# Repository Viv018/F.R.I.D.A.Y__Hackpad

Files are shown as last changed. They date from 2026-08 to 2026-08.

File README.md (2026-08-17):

# F.R.I.D.A.Y__Hackpad
This is a Macro pad with a 3x3 key pad along with a rotary encoder and a 0.91 QLED screen for my HACKCLUB project
# F.R.I.D.A.Y

A custom 3×3 macropad with a rotary encoder, 0.91" OLED, and per-key SK6812 RGB lighting, built around the Seeeduino XIAO.

I named it F.R.I.D.A.Y because I wanted something that feels like a helpful little assistant sitting on my desk and cause i am a big marvel fan.

### Features
- 9 mechanical switches (3×3 matrix)
- Rotary encoder with push button
- 0.91" 128×32 OLED display
- 8× SK6812MINI-E reverse-mount RGB LEDs
- Seeed XIAO RP2040
- Fully open source

### Photos

**Schematic**
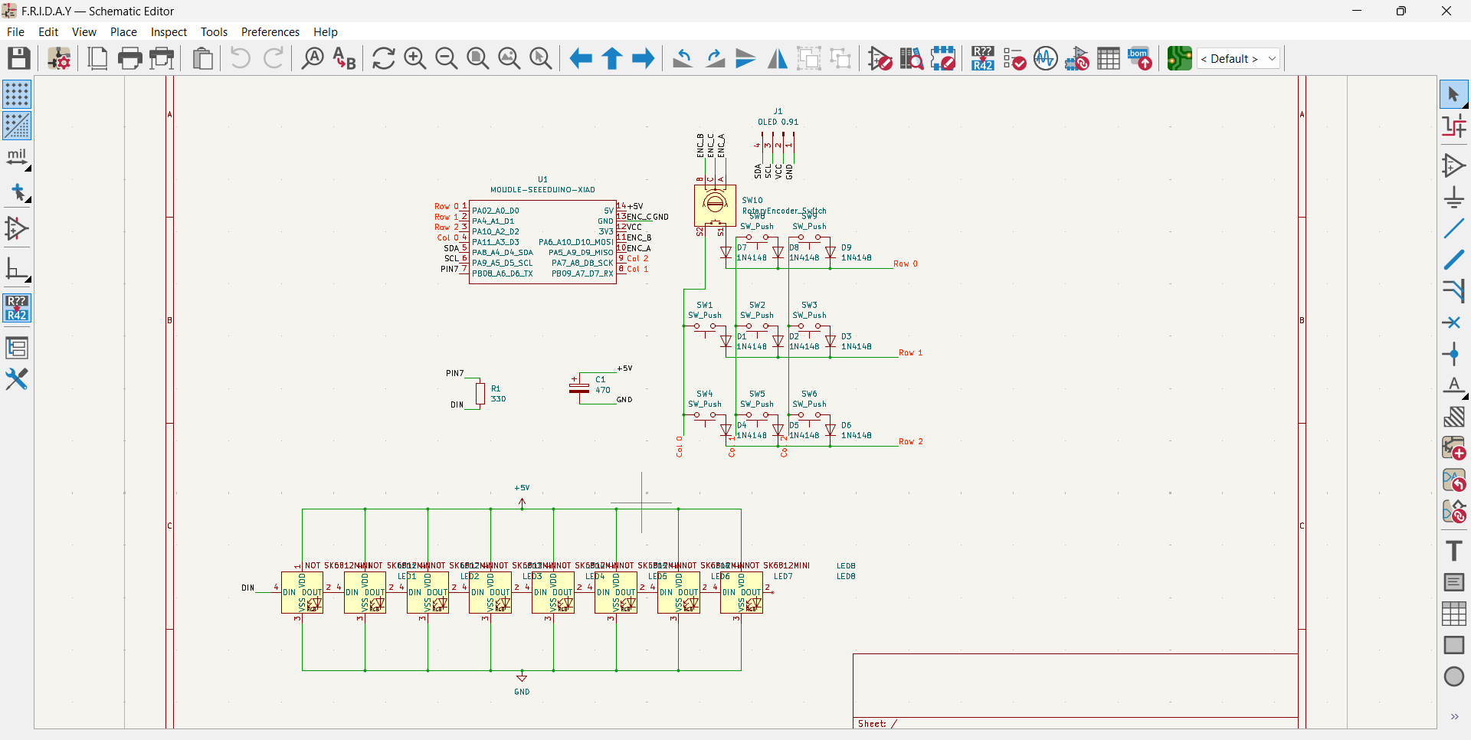
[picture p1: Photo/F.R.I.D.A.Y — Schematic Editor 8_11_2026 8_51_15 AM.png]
Schematic


**PCB**
PCB

**Case**
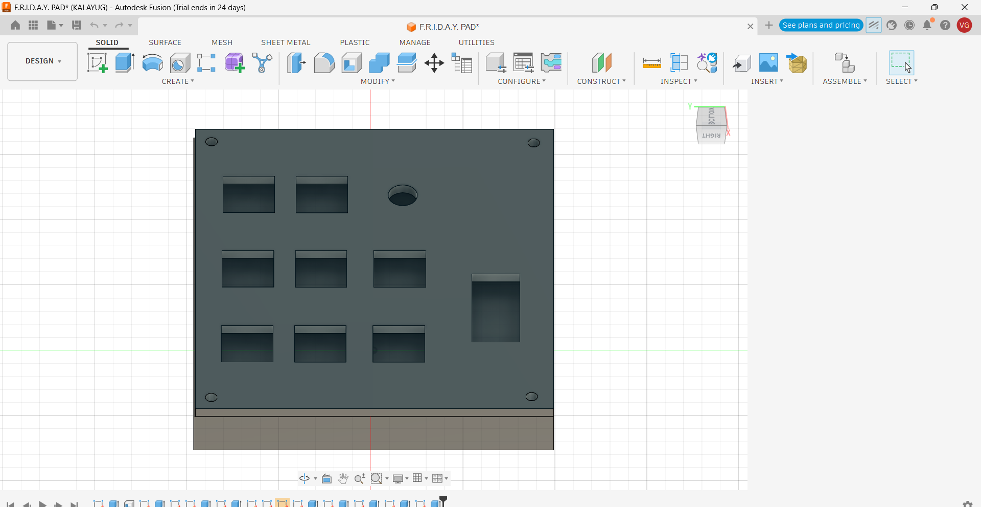
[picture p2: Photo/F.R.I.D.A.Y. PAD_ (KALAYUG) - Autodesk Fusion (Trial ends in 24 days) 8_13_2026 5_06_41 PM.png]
Case


### Bill of Materials

| Part | Quantity | Notes |
|---|---|---|
| Seeeduino XIAO | 1 | RP2040 version |
| MX-style switches | 9 | Any MX compatible |
| SK6812MINI-E | 8 | Reverse mount |
| 1N4148 diodes | 9 | |
| Rotary Encoder (EC11) | 1 | With push switch |
| 0.91" OLED | 1 | I2C, 128×32 |
| Keycaps | 9 | 1u |
| M3 screws + heat-set inserts | 4 | For the case |

### Firmware
This project uses **QMK**

The firmware is located in the `/Firmware` folder.

### Case
The case is a simple two-part sandwich design made in Fusion 360.  
STL/STEP files are available in the `/CAD` and `/production` folders.

### Credits
Designed for Hack Club’s Hackpad program by BATMANNN BABYYY

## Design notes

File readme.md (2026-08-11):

# F.R.I.D.A.Y.

This is my custom macropad, F.R.I.D.A.Y. I designed the schematic and PCB
myself in KiCad and wrote the firmware on top of QMK. It's a 3x3 key
matrix (9 keys total, one of them being the rotary encoder's own push
switch), plus the encoder for rotation input, a small OLED screen, and
RGB lighting.

## What's on it

- Seeed XIAO RP2040 as the brains
- 3x3 switch matrix (9 keys), with SW10 (the encoder's push button)
  built into the matrix as one of the 9
- A rotary encoder for scrolling / volume / media control
- A 0.91" OLED (128x32) that shows which layer is active
- 8x SK6812 addressable RGB LEDs

## Pin mapping

I worked this out straight from my schematic:

| Net | XIAO pin | RP2040 GPIO |
|---|---|---|
| Row 0 | D0 | GP26 |
| Row 1 | D1 | GP27 |
| Row 2 | D2 | GP28 |
| Col 0 | D3 | GP29 |
| SDA (OLED) | D4 | GP6 |
| SCL (OLED) | D5 | GP7 |
| PIN7 -> DIN (LEDs)  | D6 | GP0 |
| Col 1 | D7 | GP1 |
| Col 2 | D8 | GP2 |
| ENC_A | D9 | GP4 |
| ENC_B | D10 | GP3 |

Key layout, matching the silkscreen on my PCB:

```
[SW10] [SW8] [SW9]     <- SW10 is the encoder's own push button
[SW1]  [SW2] [SW3]
[SW4]  [SW5] [SW6]
```

## Firmware

Built on QMK. There are two layers - a base layer for my everyday keys
and media, and an Fn layer (hold the bottom-right key) for extra
shortcuts. The encoder does volume on the base layer and skips tracks
on the Fn layer. The OLED just shows the current layer for now.

### Building it

```bash
python3 -m pip install qmk
qmk setup
```

Then drop this whole `friday` folder into `~/qmk_firmware/keyboards/friday/`
so it looks like:

```
qmk_firmware/keyboards/friday/
├── keyboard.json
├── config.h
├── rules.mk
├── readme.md
└── keymaps/
    └── default/
        └── keymap.c
```

Compile:

```bash
qmk compile -kb friday -km default
```

That spits out `friday_default.uf2`.

### Flashing

1. Plug the XIAO RP2040 in over USB.
2. Double-tap reset to drop it into UF2 bootloader mode - a drive
   called `RPI-RP2` shows up.
3. Drag `friday_default.uf2` onto that drive. It reboots on its own
   running the new firmware.

## Notes to self

- If a key or the encoder isn't responding, check continuity on that
  net in KiCad first - the pin table above is only as good as the
  actual soldering.
- If the encoder skips two steps per detent (or does nothing), try
  changing `ENCODER_RESOLUTION` in `config.h` between 2 and 4.
- `ENC_C` on the encoder just goes to GND, nothing to configure there.
- RGB is enabled but I haven't bound any keys to control it yet - next
  thing to add.

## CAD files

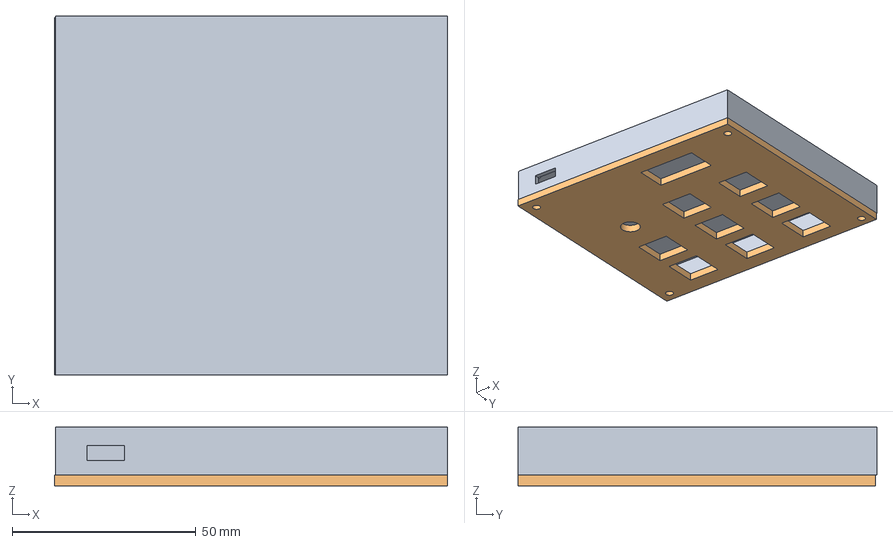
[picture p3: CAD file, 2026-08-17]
CASE/F.R.I.D.A.Y.step
107.1 x 97.8 x 16.0 mm

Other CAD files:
CASE/F.R.I.D.A.Y. PAD.f3d

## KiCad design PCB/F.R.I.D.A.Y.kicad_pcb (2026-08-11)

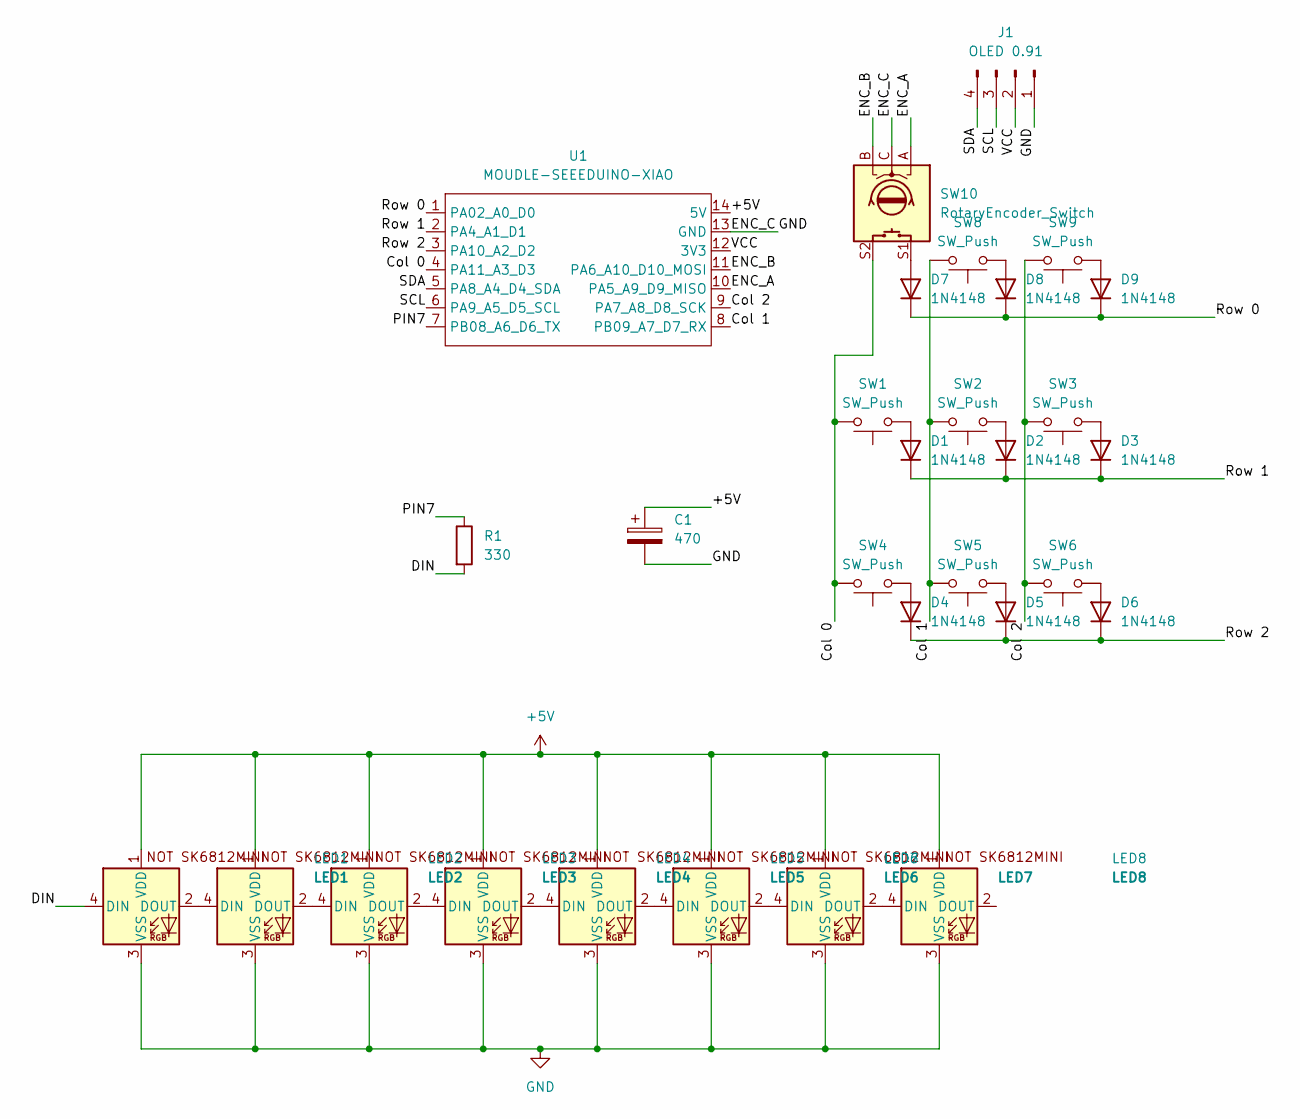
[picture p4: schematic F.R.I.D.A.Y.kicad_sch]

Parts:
C1: 470; CP_Axial_L18.0mm_D6.5mm_P25.00mm_Horizontal
D1, D2, D3, D4, D5, D6, D7, D8, D9: 1N4148; D_DO-35_SOD27_P7.62mm_Horizontal
J1: OLED 0.91; ER_OLEDM0.91_1x-I2C
LED1: LED1; LED_SK6812MINI-E_3.2x2.8mm_P1.5mm_ReverseMount
LED2: LED2; LED_SK6812MINI-E_3.2x2.8mm_P1.5mm_ReverseMount
LED3: LED3; LED_SK6812MINI-E_3.2x2.8mm_P1.5mm_ReverseMount
LED4: LED4; LED_SK6812MINI-E_3.2x2.8mm_P1.5mm_ReverseMount
LED5: LED5; LED_SK6812MINI-E_3.2x2.8mm_P1.5mm_ReverseMount
LED6: LED6; LED_SK6812MINI-E_3.2x2.8mm_P1.5mm_ReverseMount
LED7: LED7; LED_SK6812MINI-E_3.2x2.8mm_P1.5mm_ReverseMount
LED8: LED8; LED_SK6812MINI-E_3.2x2.8mm_P1.5mm_ReverseMount
R1: 330; R_Axial_DIN0207_L6.3mm_D2.5mm_P10.16mm_Horizontal
SW1, SW2, SW3, SW4, SW5, SW6, SW8, SW9: SW_Push; SW_Cherry_MX_1.00u_PCB
SW10: RotaryEncoder_Switch; RotaryEncoder_Alps_EC11E-Switch_Vertical_H20mm
U1: MOUDLE-SEEEDUINO-XIAO; XIAO-Generic-Hybrid-14P-2.54-21X17.8MM

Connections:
+5V: C1.1, LED1.1 (VDD), LED2.1 (VDD), LED3.1 (VDD), LED4.1 (VDD), LED5.1 (VDD), LED6.1 (VDD), LED7.1 (VDD), LED8.1 (VDD), U1.14 (5V)
/Col 0: SW1.2, SW4.2, SW10.S2, U1.4 (PA11_A3_D3)
/Col 1: SW2.2, SW5.2, SW8.2, U1.8 (PB09_A7_D7_RX)
/Col 2: SW3.2, SW6.2, SW9.2, U1.9 (PA7_A8_D8_SCK)
/DIN: LED1.4 (DIN), R1.2
/ENC_A: SW10.A, U1.10 (PA5_A9_D9_MISO)
/ENC_B: SW10.B, U1.11 (PA6_A10_D10_MOSI)
/PIN7: R1.1, U1.7 (PB08_A6_D6_TX)
/Row 0: D7.1 (K), D8.1 (K), D9.1 (K), U1.1 (PA02_A0_D0)
/Row 1: D1.1 (K), D2.1 (K), D3.1 (K), U1.2 (PA4_A1_D1)
/Row 2: D4.1 (K), D5.1 (K), D6.1 (K), U1.3 (PA10_A2_D2)
/SCL: J1.3, U1.6 (PA9_A5_D5_SCL)
/SDA: J1.4, U1.5 (PA8_A4_D4_SDA)
/VCC: J1.2, U1.12 (3V3)
GND: C1.2, J1.1, LED1.3 (VSS), LED2.3 (VSS), LED3.3 (VSS), LED4.3 (VSS), LED5.3 (VSS), LED6.3 (VSS), LED7.3 (VSS), LED8.3 (VSS), SW10.C, U1.13 (GND)
unnamed: D1.2 (A), SW1.1
unnamed: D2.2 (A), SW2.1
unnamed: D3.2 (A), SW3.1
unnamed: D4.2 (A), SW4.1
unnamed: D5.2 (A), SW5.1
unnamed: D6.2 (A), SW6.1
unnamed: D7.2 (A), SW10.S1
unnamed: D8.2 (A), SW8.1
unnamed: D9.2 (A), SW9.1
unnamed: LED1.2 (DOUT), LED2.4 (DIN)
unnamed: LED2.2 (DOUT), LED3.4 (DIN)
unnamed: LED3.2 (DOUT), LED4.4 (DIN)
unnamed: LED4.2 (DOUT), LED5.4 (DIN)
unnamed: LED5.2 (DOUT), LED6.4 (DIN)
unnamed: LED6.2 (DOUT), LED7.4 (DIN)
unnamed: LED7.2 (DOUT), LED8.4 (DIN)

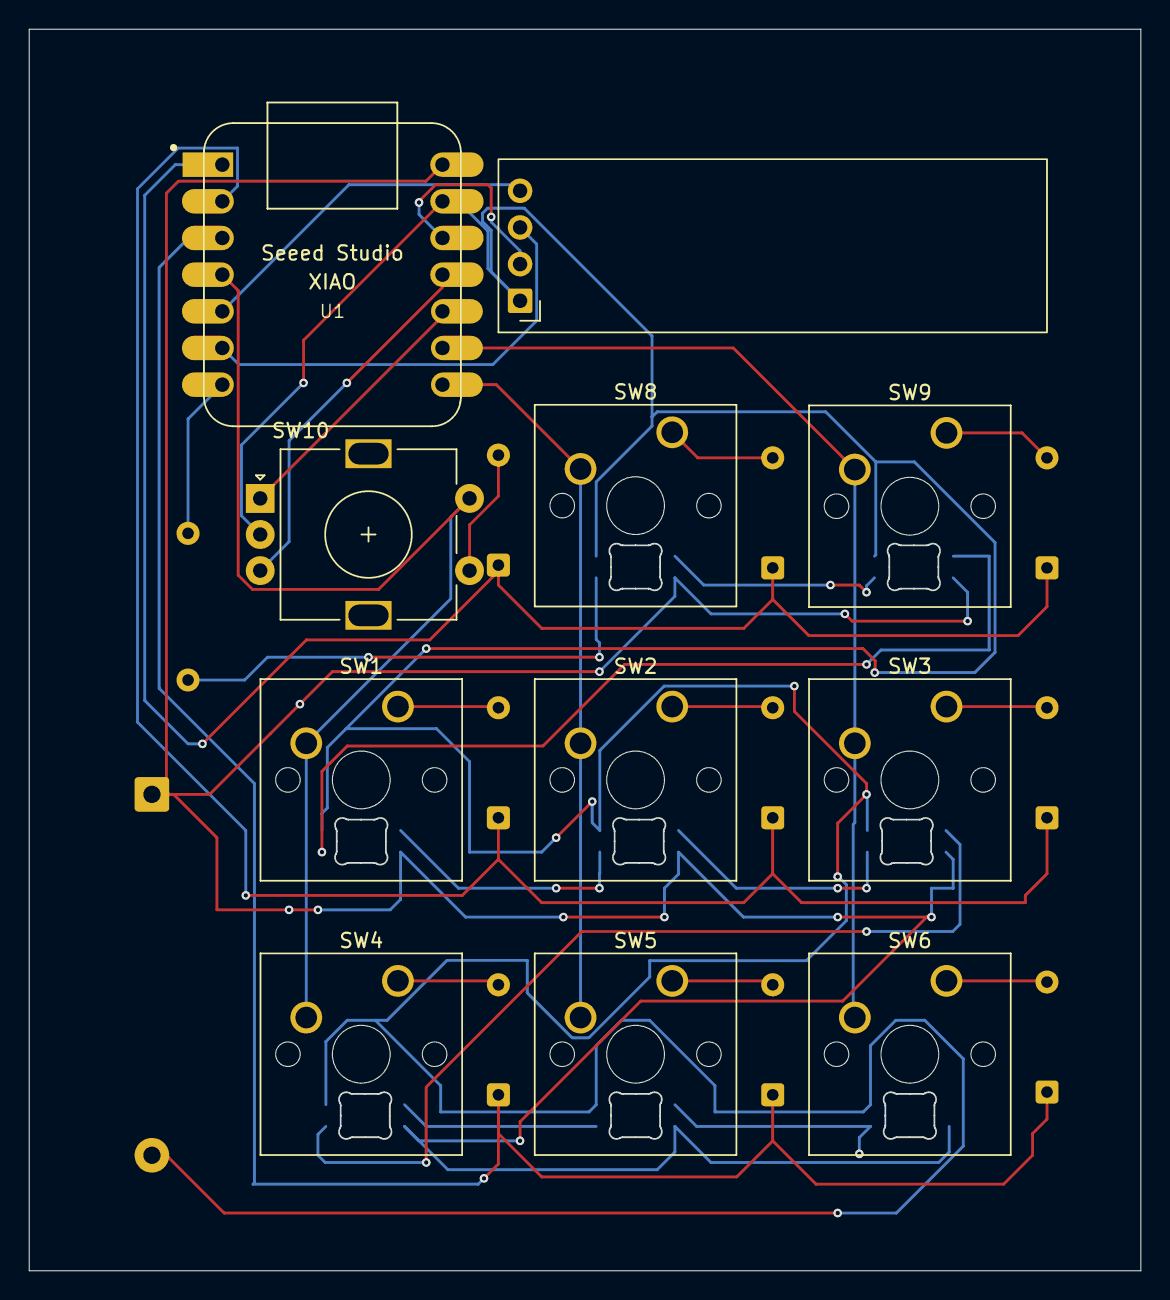
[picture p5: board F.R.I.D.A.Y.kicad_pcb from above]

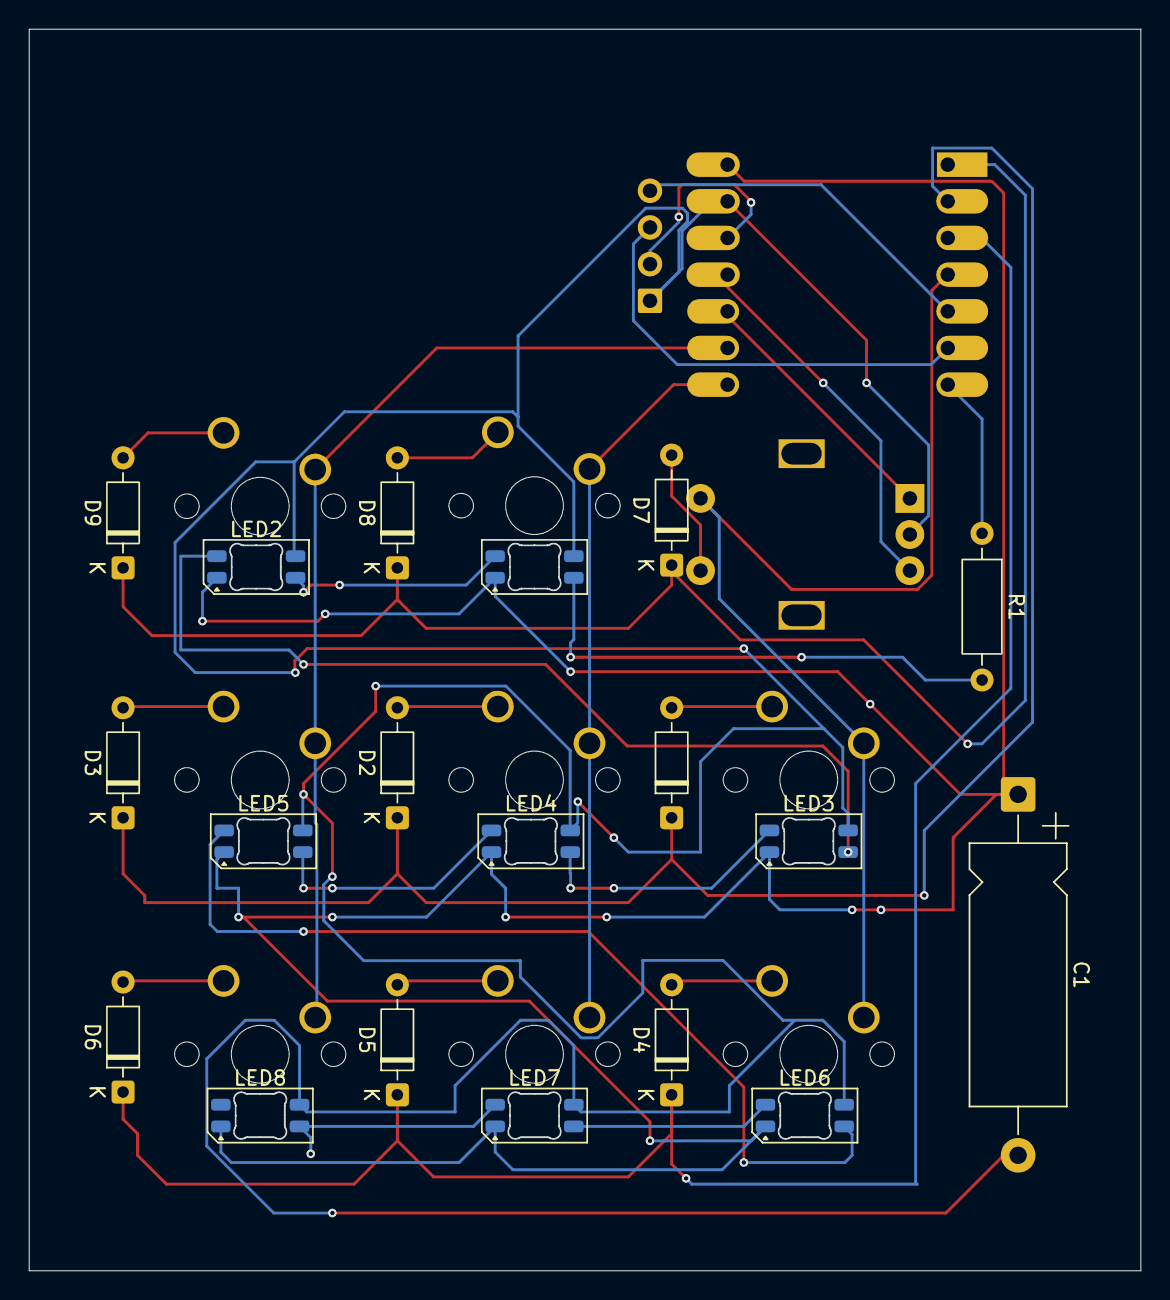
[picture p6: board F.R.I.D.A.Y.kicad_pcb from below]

Board: 2 copper layers, 77.0 x 86.0 mm, 30 parts (19 on the bottom side), 31 nets.

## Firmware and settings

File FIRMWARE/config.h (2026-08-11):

#pragma once

/* OLED is on SDA=GP6 / SCL=GP7 (D4/D5 on the XIAO silkscreen) */
#define I2C_DRIVER I2CD1
#define I2C1_SDA_PIN GP6
#define I2C1_SCL_PIN GP7

/* Your J1 connector is a 0.91" SSD1306, which is 128x32, not the 128x64 default */
#define OLED_DISPLAY_128X32

/* Most rotary encoders detent every 4 pulses - lower this to 2 if turning
   one detent skips two steps, or raise it if one detent does nothing */
#define ENCODER_RESOLUTION 4

/* Debounce time in ms - raise if you get double presses on the tactile switches */
#define DEBOUNCE 5

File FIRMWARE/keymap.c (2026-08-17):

#include QMK_KEYBOARD_H

enum layers {
    _BASE = 0,
    _FN
};

// Physical layout, matching my PCB silkscreen:
//
//   [SW10]  [SW8]  [SW9]      <- SW10 = encoder push button (row0/col0)
//   [SW1]   [SW2]  [SW3]
//   [SW4]   [SW5]  [SW6]
//
// Edit the keycodes below to whatever your macros/shortcuts should be.
// Full keycode reference: https://docs.qmk.fm/keycodes

const uint16_t PROGMEM keymaps[][MATRIX_ROWS][MATRIX_COLS] = {
    [_BASE] = LAYOUT(
        KC_MUTE, KC_7,     KC_8,
        KC_1,    KC_2,     KC_3,
        KC_4,    KC_5,     MO(_FN)
    ),

    [_FN] = LAYOUT(
        KC_TRNS, KC_F7,    KC_F8,
        KC_F1,   KC_F2,    KC_F3,
        KC_F4,   KC_F5,    KC_TRNS
    )
};

#if defined(ENCODER_MAP_ENABLE)
// Rotate CCW, rotate CW for each layer
const uint16_t PROGMEM encoder_map[][NUM_ENCODERS][NUM_DIRECTIONS] = {
    [_BASE] = { ENCODER_CCW_CW(KC_VOLD, KC_VOLU) },
    [_FN]   = { ENCODER_CCW_CW(KC_MPRV, KC_MNXT) },
};
#endif

#ifdef OLED_ENABLE

oled_rotation_t oled_init_user(oled_rotation_t rotation) {
    return OLED_ROTATION_0;
}

bool oled_task_user(void) {
    oled_write_P(PSTR("F.R.I.D.A.Y.\n"), false);
    oled_write_P(PSTR("------------\n"), false);

    switch (get_highest_layer(layer_state)) {
        case _BASE:
            oled_write_P(PSTR("Layer: Base\n"), false);
            break;
        case _FN:
            oled_write_P(PSTR("Layer: Fn\n"), false);
            break;
        default:
            oled_write_P(PSTR("Layer: ?\n"), false);
            break;
    }

    return false;
}

#endif

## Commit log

2026-08-11 Update README with project details and features
    Expanded project description and added features, photos, bill of materials, firmware, case design details, and credits.
2026-08-13 Rename F.R.I.D.A.Y. PAD.f3d to PCB/F.R.I.D.A.Y. PAD.f3d
    [F.R.I.D.A.Y. PAD.f3d]
2026-08-13 Rename F.R.I.D.A.Y.kicad_sch to PCB /F.R.I.D.A.Y.kicad_sch
    [F.R.I.D.A.Y.kicad_sch]
2026-08-13 Rename F.R.I.D.A.Y. PAD.f3d to F.R.I.D.A.Y. PAD.f3d
    [F.R.I.D.A.Y. PAD.f3d]
2026-08-13 Update PCB image with new HTML format
2026-08-13 Update PCB image link in README.md
2026-08-13 Fix PCB image filename formatting in README.md
2026-08-13 Update PCB image filename in README
2026-08-13 Rename F.R.I.D.A.Y — PCB Editor 8_10_2026 3_42_48 PM.png to Photo/F.R.I.D.A.Y — PCB Editor 8_10_2026 3_42_48 PM.png
2026-08-13 Rename F.R.I.D.A.Y — Schematic Editor 8_11_2026 8_51_15 AM.png to Photo/F.R.I.D.A.Y — Schematic Editor 8_11_2026 8_51_15 AM.png
2026-08-17 Rename F.R.I.D.A.Y — Schematic Editor 8_11_2026 8_51_15 AM.png to Schematic Editor.png
2026-08-17 Rename F.R.I.D.A.Y. PAD_ (KALAYUG) - Autodesk Fusion (Trial ends in 24 days) 8_13_2026 5_06_41 PM.png to Case.png
2026-08-17 Fix schematic image link in README
    Updated schematic image reference in README.
2026-08-17 Rename Schematic Editor.png to Image/Schematic_Editor.png
